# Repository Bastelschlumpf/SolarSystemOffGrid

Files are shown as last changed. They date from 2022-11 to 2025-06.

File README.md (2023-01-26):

## Off Grid Solar System
   **Solar system for use as an emergency power supply with automatic switching to mains power in case of lack of solar 
     power with display on an E-Ink display via MQQT.**

### Description
   The goal of this facility was to ask; what happens in the event of a power outage.  
   Which electrical devices in the house are the most critical here and should continue to function in this case.
   At least for some time.  
   In my case, this would be the freezers and the oil heating.
   A continued functioning of the solar circulation pump would also be beneficial.  
   What good are hundreds of liters of heating oil in the tank if the house remains cold because of the 200W that the oil burner needs.  
   On television, computer and also the short-time cooking on an electric stove should be able to be renounced to the emergency.  
   In addition, this system should monitor the battery capacity and in case the sun does not shine enough automatically switch to house power.  
   And since I am a Tasmota and ESP fan, the whole thing should be additionally monitored via E-Ink display and MQQT via my IoBroker.

### Disclaimer
   I don't take any responsibility nor liability for using this software nor for the 
   installation or any tips, advice, videos, etc. given by any member of this site or any related site.  
   Attention this plant is in the making and not yet tested.
   In particular, the behavior in summer months and the interaction with the batteries has not yet been tested by me
   extensively tested in practice. 

### Safety aspects
  * [Some thoughts about security](docs/SafetyAspects.md)

### Circuit
   Circuit diagram with pictures of the components   
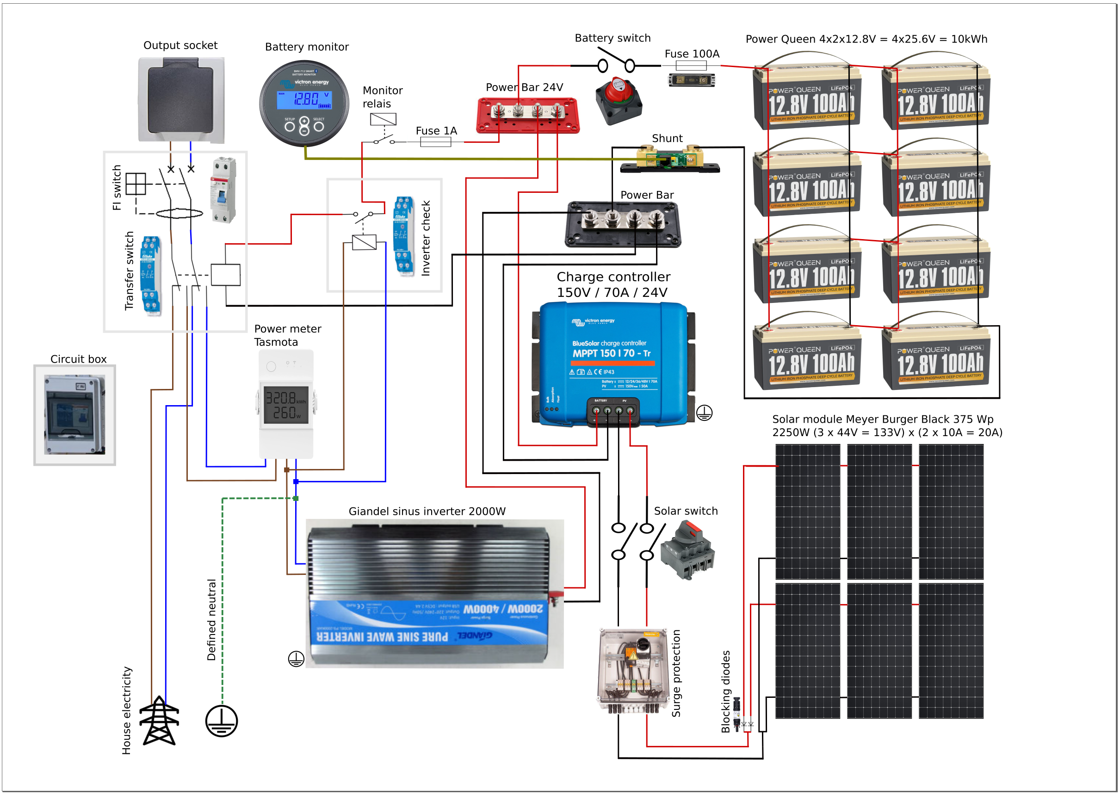
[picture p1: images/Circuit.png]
Circuit
   

   Circuit diagram with real components on the control panel
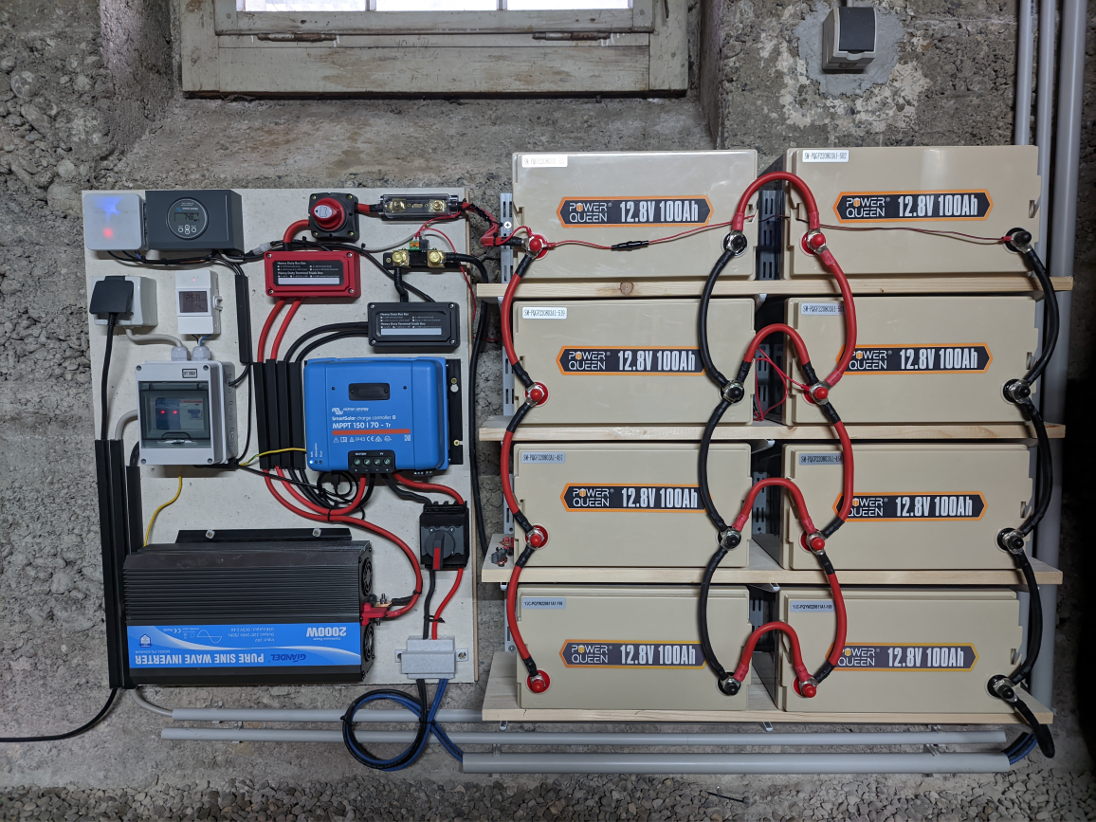
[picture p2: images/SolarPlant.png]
Circuit on the control panel Solar plant
     
   Manuals of the components: See manuals folder

### Pictures of the solar panels and installation
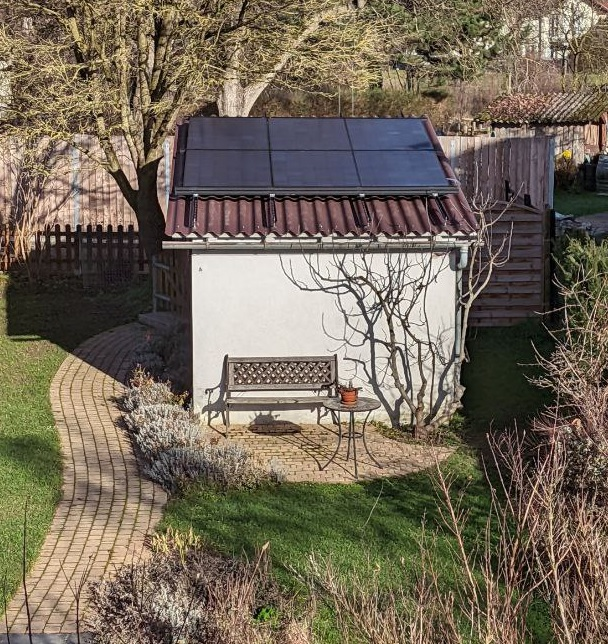
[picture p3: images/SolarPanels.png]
Solar panels
   

  * [See pictures of the installation](docs/TheSolarInstallation.md)

### Victron Modules and Settings
  * [See Victron modules and settings](docs/Victron.md)

### Power consumption monitoring with Tasmota
  * [See Tasmota (Sonoff) Elite 20A](docs/Tasmota.md)

### Victron MQQT Bridge to IoBroker
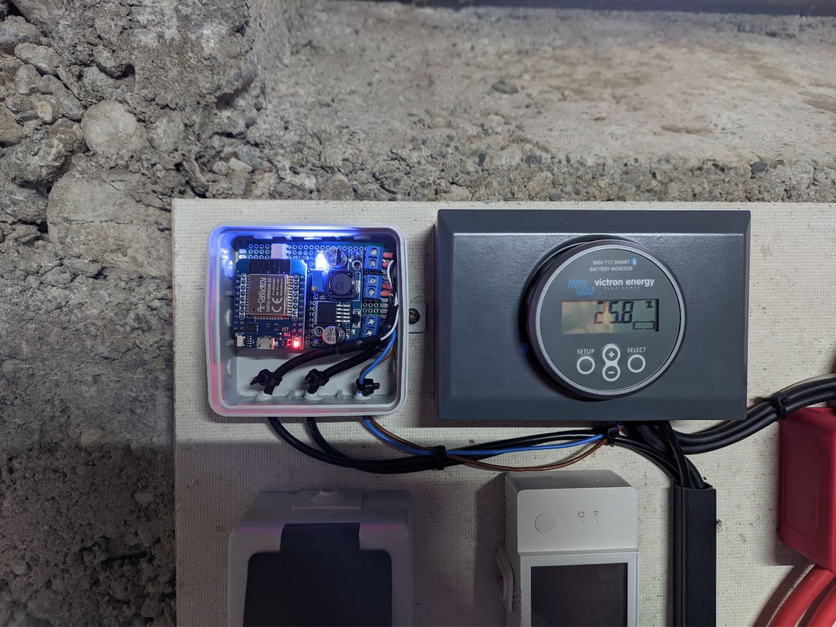
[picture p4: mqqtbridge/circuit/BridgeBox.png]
BridgeBox
   
   IoBroker View: Not beautiful but everything on it  
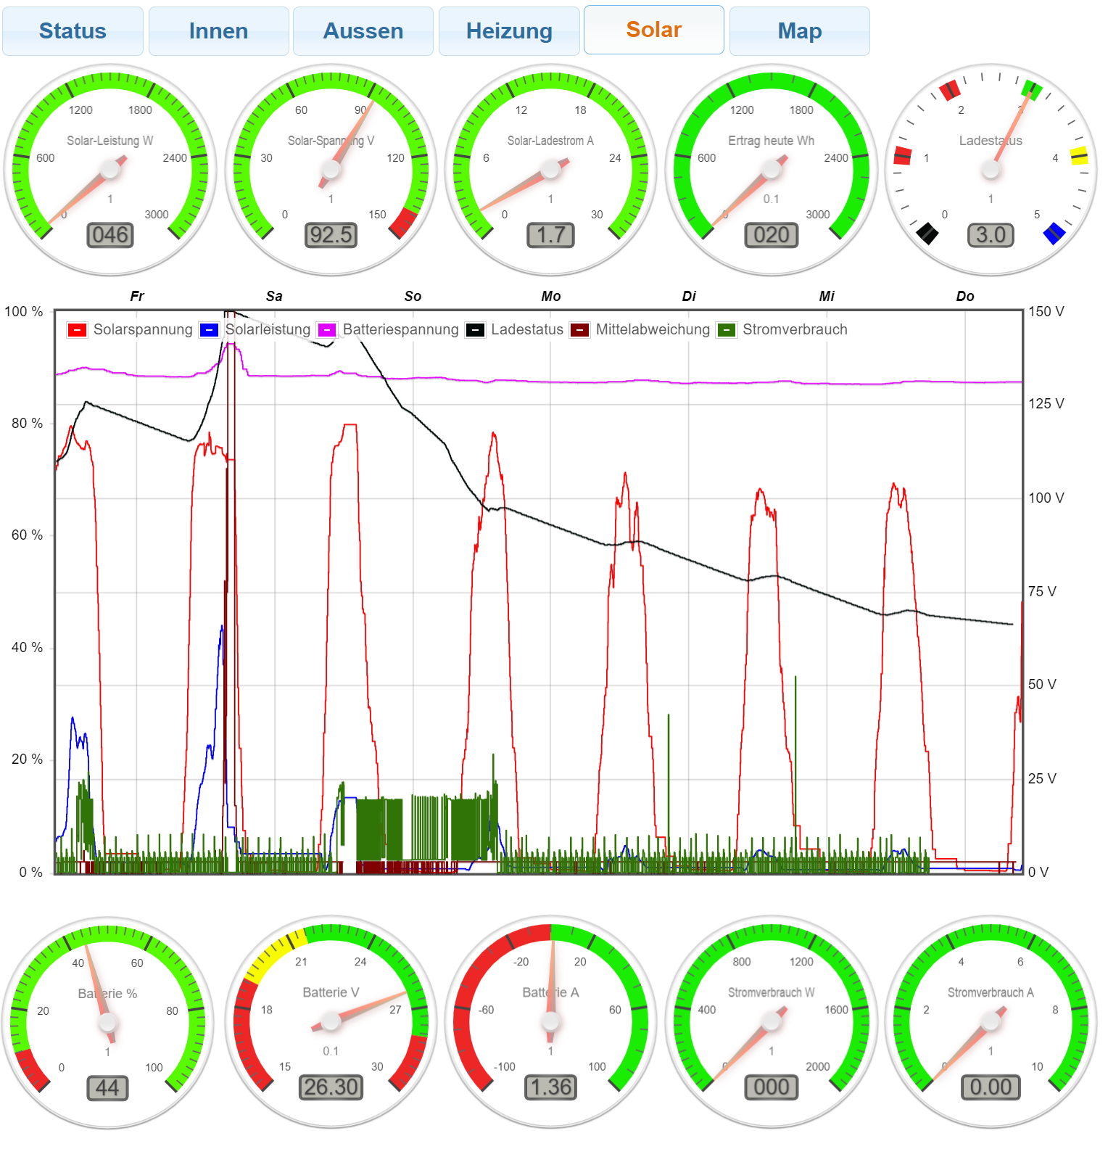
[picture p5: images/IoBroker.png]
IoBrokerView
   
  * [See Victron to IoBroker MQQT Bridge](docs/VictronMQQTBridge.md)

### Wall mounted status display via  E-Ink display (M5Paper)
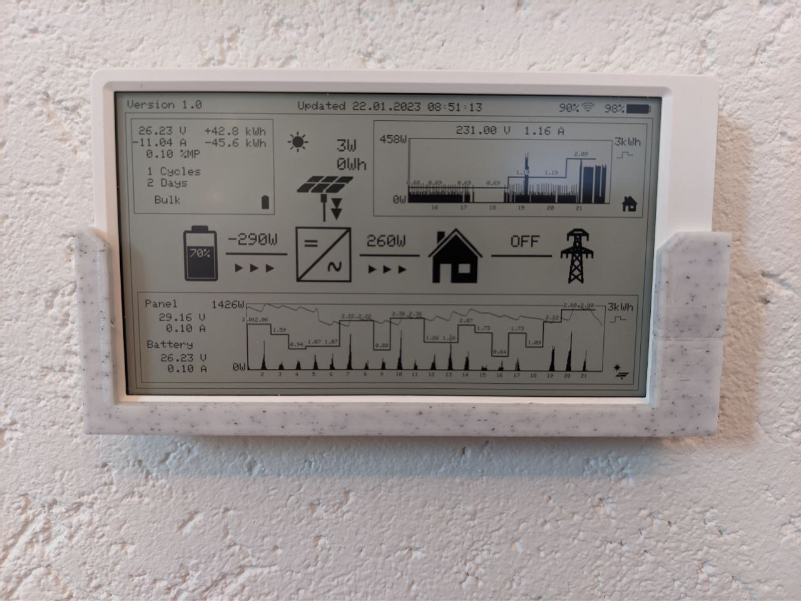
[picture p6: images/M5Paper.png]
Circuit M5Paper
   
  * [See Status display](docs/StatusDisplay.md)

### Shopping list
  * [See Shopping list](docs/ShoppingList.md)

### License
   This program is licensed under GPL-3.0

### Thanks
   * Thanks to 'Power Queen' for the great support and advice.
   * https://www.arduino.cc
     *Thanks to the Arduino community with all its incredible possibilities and support.** 
   * https://github.com/arendst/Sonoff-Tasmota
     *Thanks to Theo Arends for his great home automation software project with all the detailed esp functionality.*
   * http://fritzing.org/home
     *Thanks to the fritzing team for this very intuitive usable software.* 
     I could create my circuit in Fritzing with only a half day.
   * And a special thanks to the support of the local electrician for advice on solar issues and for the 
     Ordering electrical components like cables, surge protectors and solar panels.
     And many thanks for the energetic support of my brother in pulling cables, assembling
     components and also for the good advice.

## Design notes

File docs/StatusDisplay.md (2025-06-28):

## Status display via  E-Ink display (M5Paper)

### Compiling instraction

Board **M5Stack 2.1.4**

Library  
  **M5EPD 0.1.5 (https://github.com/m5stack/M5EPD)**  
  **RTCLib 2.1.4 (https://github.com/adafruit/RTClib)**  
  **Time 1.6.1 (https://playground.arduino.cc/Code/Time)**   
  Arduino flash with default settings

### Monitor description

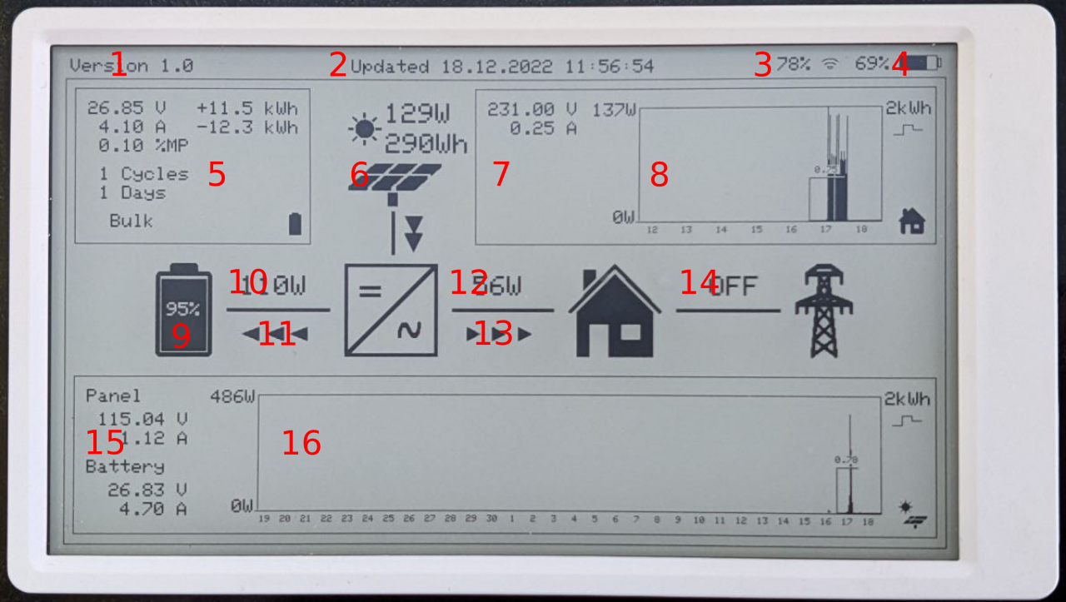
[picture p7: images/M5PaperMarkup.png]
Circuit M5Paper


The entire solar system should have a display on which all important status messages and values are visible.  
In addition, two diagrams about the power curve should be displayed.  
By simple symbols it should be directly recognizable in which direction the power is currently flowing and  
whether a connection is switched on or off.  
If errors occur in the battery monitor module or the charge controller,  
these should be displayed with priority.
Furthermore, it should be visible if the data is no longer supplied by the IoBroker or if it is outdated.  

Here is the description of each area.

|Label |Description |
|---|---|
|<span style="color: red">  1 </span>| Internal monitor version. |
|<span style="color: red">  2 </span>| The date and time of the last display update. |
|<span style="color: red">  3 </span>| The strength of the wifi connection with value and symbol. |
|<span style="color: red">  4 </span>| The current state of charge of the battery with value and symbol. |
|<span style="color: red">  5 </span>| All detailed information of the battery monitor (Victron BMV-712).
| | - The current voltage |
| | - The current charge or discharge current |
| | - The deviation of the average point voltage |
| | - How much charge was charged in total |
| | - How much charge has been removed in total |
| | - The number of charge cycles |
| | - How many days since the last full charge |
| | - The current charging mode |
| | In case of an error, the problem is displayed here instead. |
|<span style="color: red">  6 </span>| Display of the solar panel icon with the current watt and the power gained today |
|<span style="color: red">  7 </span>|  The details of output power monitoring (Tasmota Elite) |
| | - Grid voltage |
| | - Current current consumption |
|<span style="color: red">  8 </span>| Statistical data of consumed energy for the last 7 days (watts and kWh) |
|<span style="color: red">  9 </span>| The battery icon with the current charge level |
|<span style="color: red"> 10 </span>| The current charging (+) or discharging (-) power. |
|<span style="color: red"> 11 </span>| Arrow direction of loading or unloading |
|<span style="color: red"> 12 </span>| The current energy going to the end users. |
|<span style="color: red"> 13 </span>| The arrows indicate whether the final consumers are supplied by the solar system. |
|<span style="color: red"> 14 </span>| The arrows indicate whether the end users draw power from the grid otherwise 'OFF'. |
|<span style="color: red"> 15 </span>| All detailed information of the charge controler (Victron MPPT 150/70). |
| | The voltage of the solar panels |
| | The delivered current of the solar panels |
| | The current battery charging voltage |
| | The current battery charging current |
|<span style="color: red"> 16 </span>| Statistical data of the charge controller in watts and kWh and the battery charge. |

### Wall mount

And here the whole thing with a wall mount made by 3D printing

   See https://www.thingiverse.com/thing:4767014  
   Wall mount WallMount

### Inplate 6 Plus version

   I have also ported the M5Paper version to Inkplate 6 Plus for testing.
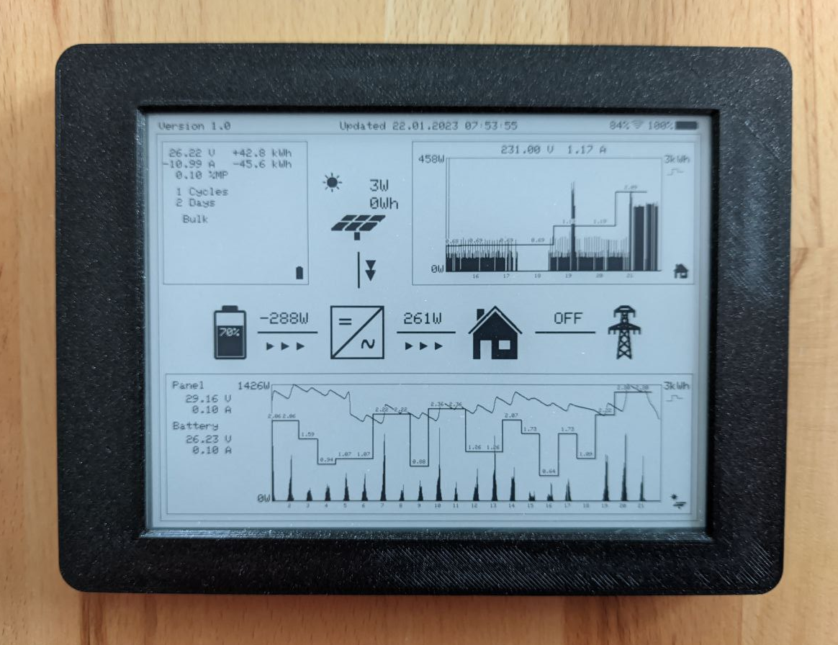
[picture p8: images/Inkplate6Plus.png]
Inkplate 6 Plus


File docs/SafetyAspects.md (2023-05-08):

### Some thoughts about security

- The solar panels are protected against lightning strikes by an overvoltage protection.
- The parallel connected solar panels are protected by a blocking diode so that the current does not flow into the other series connection.
- Directly after the solar panels a circuit breaker is installed in the garage so that the solar voltage can be disconnected from the grid on site.
- The solar connection line in the basement also has a circuit breaker so that the solar voltage can also be disconnected in the basement.
- The solar charge controller has reverse polarity protection, overload protection and temperature protection and also switches off automatically in case of other errors.
- The battery monitor monitors the battery voltage, charge and discharge current, as well as the midpoint voltage and temperature of the battery bank.
- The inverter has overvoltage protection, undervoltage protection and temperature monitoring.
- The batteries have an integrated battery management system. This protects each battery from overvoltage, undervoltage, overtemperature and undertemperature below 0 degrees Celsius.
- In addition, the battery management system also protects against short circuit.
- The battery bank can be disconnected from the system by a power disconnect switch.
- The battery bank connection is protected by a 100A fuse from the system.
- The power switching relay circuit and the supply voltage of the battery monitoring system is protected against short circuit by a 1A fuse.
- The output of the inverter is protected against fault currents by a RCD fuse.
- The output of the inverter can be remotely disconnected from the grid via a power monitoring system via Wifi.
- According to the installation connection standard and so that the RCD is functional, one phase of the inverter is defined by means of grounding to a defined potential.
- The complete system sends its status data to a home control system (IoBroker).
- An E-Ink display shows all important system data and statistics.
- The circuit is fireproof mounted on a Fermacell panel.
- The connections with higher voltage are covered finger-safe.
- A fire alarm is mounted in the basement room.
- Furthermore, a special extinguisher for lithium-ion batteries is mounted in some distance.

I hope I have not overlooked anything fundamentally important.

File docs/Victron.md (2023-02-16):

### Victron Modules and Settings

I use 2 modules from Victron.
A charge controller (SmartSolar MPPT 150/70) to bring the solar energy of the solar panels into the battery and  
 a battery monitor (Smart BMV-712) that monitors the state of charge of my batteries by means of a shunt.

Victron BMV-712 with enhousing  
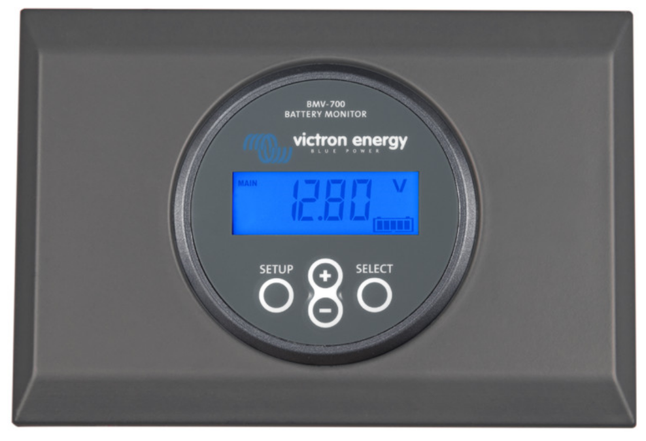
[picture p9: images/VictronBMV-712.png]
Victron BMV-712 Smart BMV


Victron BMV-712 shunt  
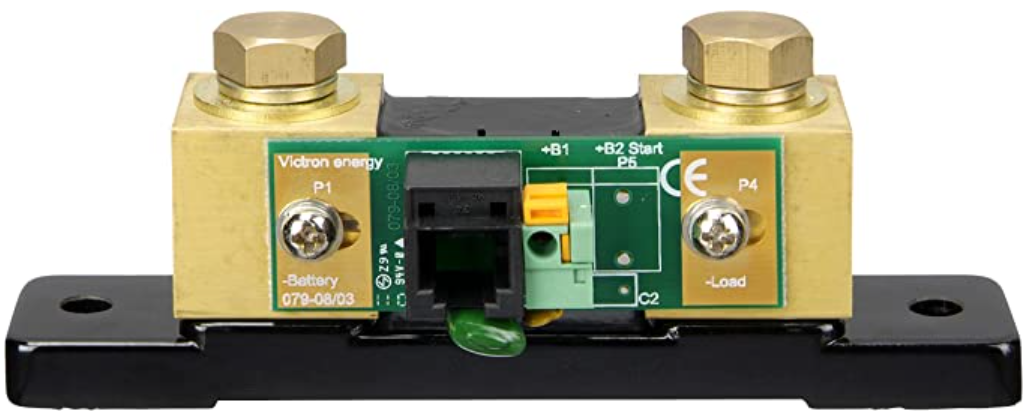
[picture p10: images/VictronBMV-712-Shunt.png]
Victron BMV-712 shunt Smart BMV


Victron Smart Battery Monitor  
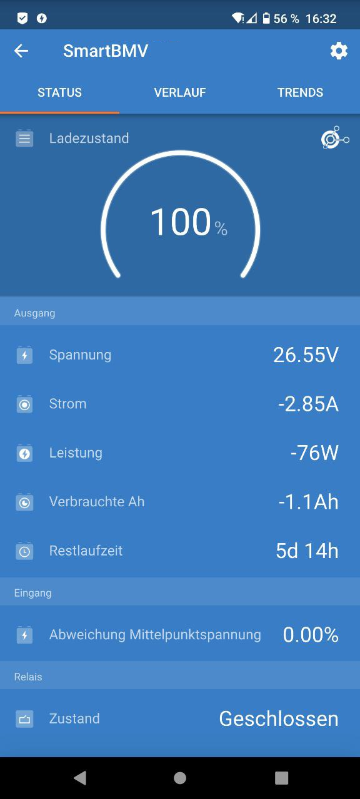
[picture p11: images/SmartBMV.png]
Victron BMV Monitor Smart BMV


Victron Smart MPPT 150/70  
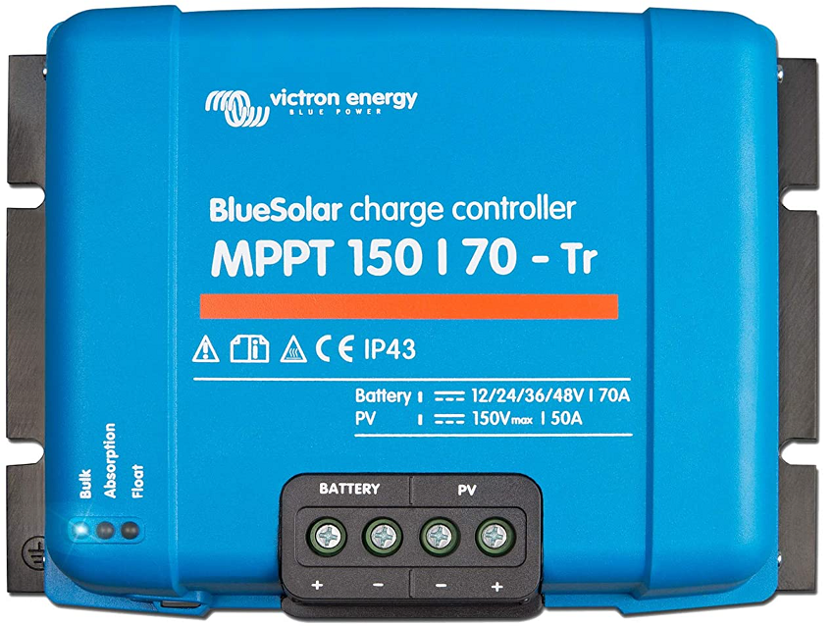
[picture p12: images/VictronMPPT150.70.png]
Victron MPPT Smart MPPT


Victron Smart MPPT Monitor  
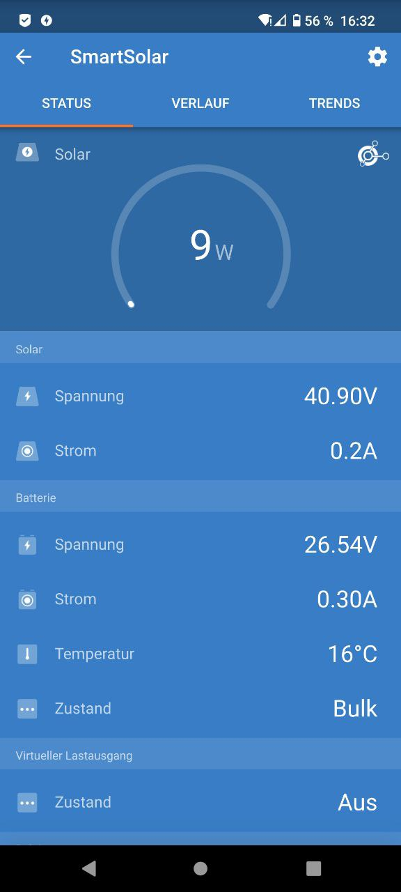
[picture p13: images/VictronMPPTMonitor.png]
Victron MPPT Monitor Smart MPPT Monitor


### Smart MPPT 150/70 Settings

|Name |Value |Description  |
|-----|---|---|
|Battery voltage |24V |2 times each Power Queen Lifepo4 Battrien in series |
|Max charge current | 70A | The Power Queen batteries can handle max 100A charge currents but the charge controller can only handle max 70A |
|Charger enabled | enabled | To safe the power in the batteries |
|Battery preset | Power Queen | I make a copy of the LiFePo4 settings and have given their own name 'Power Queen'. |
|Absorption voltage | 28.8V | In the description of Power Queen it says 'Recommended charging voltage 14.2V to 14.6V therefore 2 times 14.4V = 28.8V |
|Float voltage | 27.6V | In the description of Power Queen it says 'float charge voltage 13.8V therefore 2 times 13.8V = 27.6V |
|Equalization voltage | disabled | Disabled for LiFePo4 battries |
|Expert settings |  |  |
|Re-bulk voltage offset | 1.8V | Recommend 27V for re-bulk so it will be 28.8V - 1.8V = 27V. |
|Absorption duration | adaptive | Recommend adataptive for Power Queen |
|Absorption time | 2h | Should be enough |

### Smart BMV-712 Settings

|Name |Value |Description  |
|-----|---|---|
|Battery capacity | 400Ah | 4 x 2 x 100Ah Power Queen LiFePo4 batteries = 400Ah |
|Charged voltage | 27V | According to the Power Queen documentation, the voltage at 100% is 13.5V, i.e. times 2 = 27V. |
|Discharge floor | 20% | LiFePo4 batteries can be discharged up to 20%. |
|Tail current | 2.0% | 2% at 400Ah = 8A should be enough to switch to float. |
|Charged detection time | 3m | Should be enough. |
|Peukert exponent | 1.05 | Special value for LiFePo4 batteries. |
|Charge efficiency factor | 99% | Special value for LiFePo4 batteries. |
|Current threshold | 0.10A | Default for LiFePo4 batteries. |
|Time-to-go averaging period | 12m | Especially maximum (12m) since in refrigerators very changeable power demand. |
|Relais settings |  |  |
|Relais-Modus | Standard |  |
|Relais inverted | yes | In the event of a battery power failure, the system automatically switches to mains power. |
|Relay low charge | 10% - 90% | I.e. if the battery charge drops below 10% then the relay opens and the system goes on mains power until the charge is back to 90%. |

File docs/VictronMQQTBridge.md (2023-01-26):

### Victron MQQT Bridge

   **A bridge to send all the victron ve.direct data to my IoBroker via MQQT**
   
   The bridge should be connected by optocouplers galvanically isolated to both Victron devices, 
   the MPPT charge controller and the battery monitoring device.

   The software should read both ve.direct ports, respect the checksum so that no data garbage 
   arrives at my IoBroken and then send only every 10 seconds to the ioBroker.

   Circuit diagram with pictures of the components   
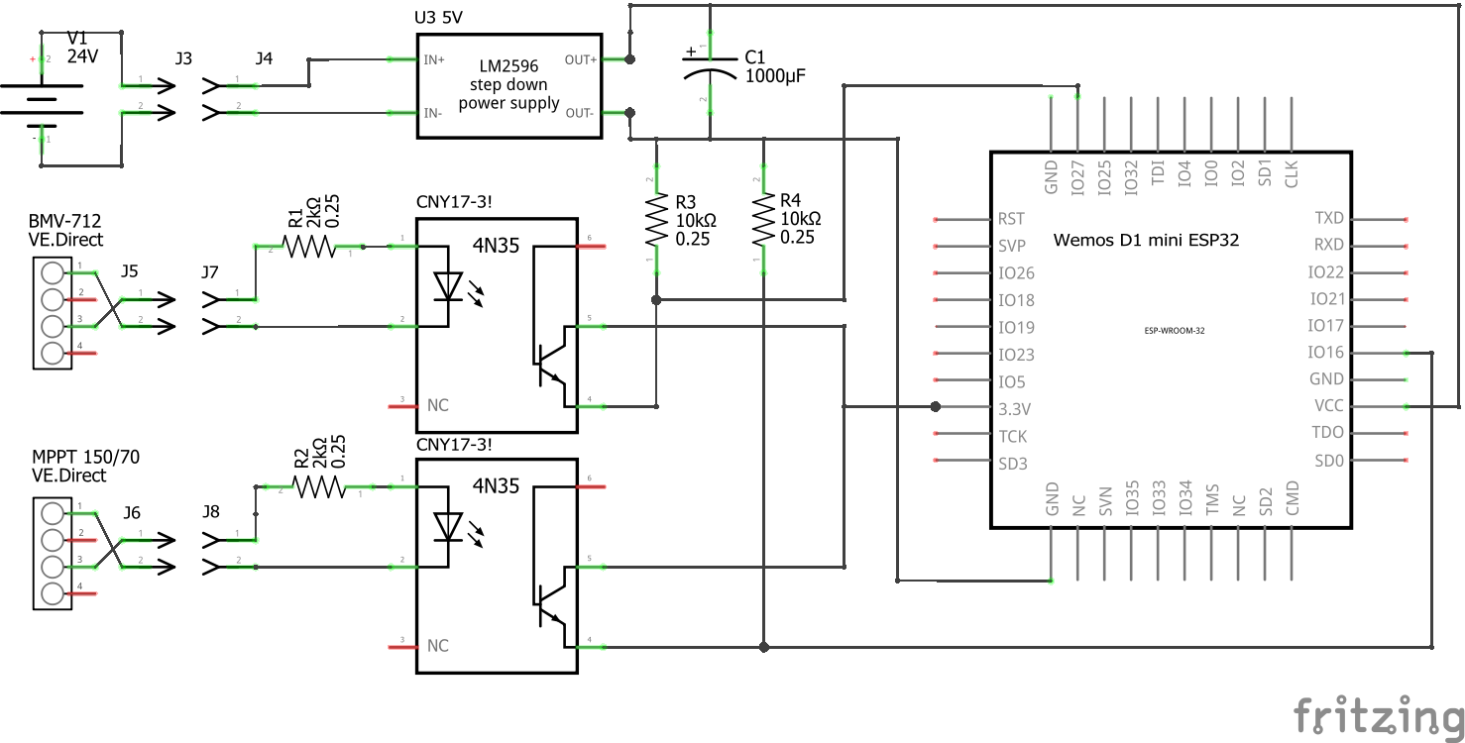
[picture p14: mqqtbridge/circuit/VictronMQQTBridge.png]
Victron To MQQT Bridget Victron To MQQT Bridge
   
   I had problems with the 4N35 optocoupler but with the CNY17-3 it works fine.  
   And very important: The LM2596 is great but the output voltage must be smoothed, 1000μF is a bit much but never mind.

   Finished Board  
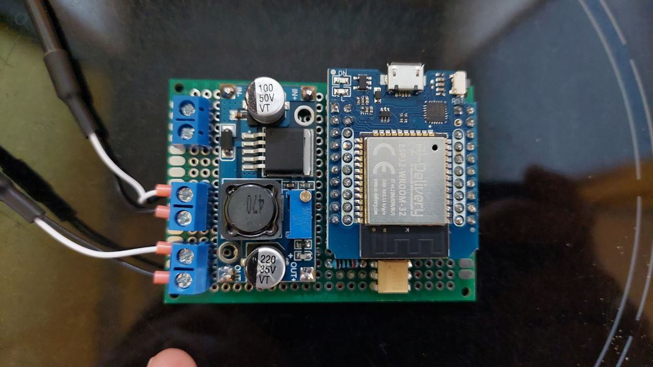
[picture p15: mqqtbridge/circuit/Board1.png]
Board1 Board 1
   

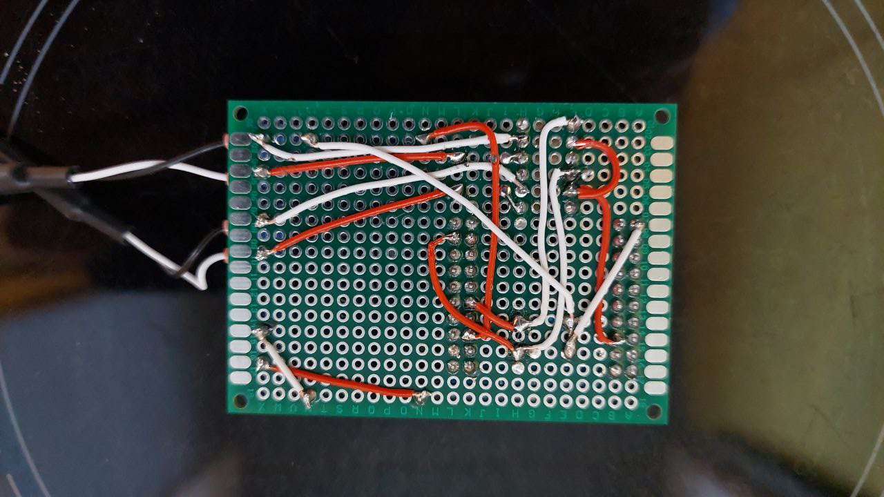
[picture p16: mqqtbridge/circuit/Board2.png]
Board2 Board 2
   
   I used a Victron VE.Direct TX digital output cable.

   On the subject of connecting the ve.direct interface via Optocopler, I found this page. 
   https://www.tarthorst.net/victron-ve-direct/  
   Thank you for this example.  
   I have modified it a bit, I now switch the 3.3V input then I do not have to invert the signal.  
   And I tested the series resistor. It works best with 2k ohms at the optocoupler input and 10k ohms at the ESP32 input

   The box at the solar installation
   BridgeBox

   The data packets arrive in my IoBroker.
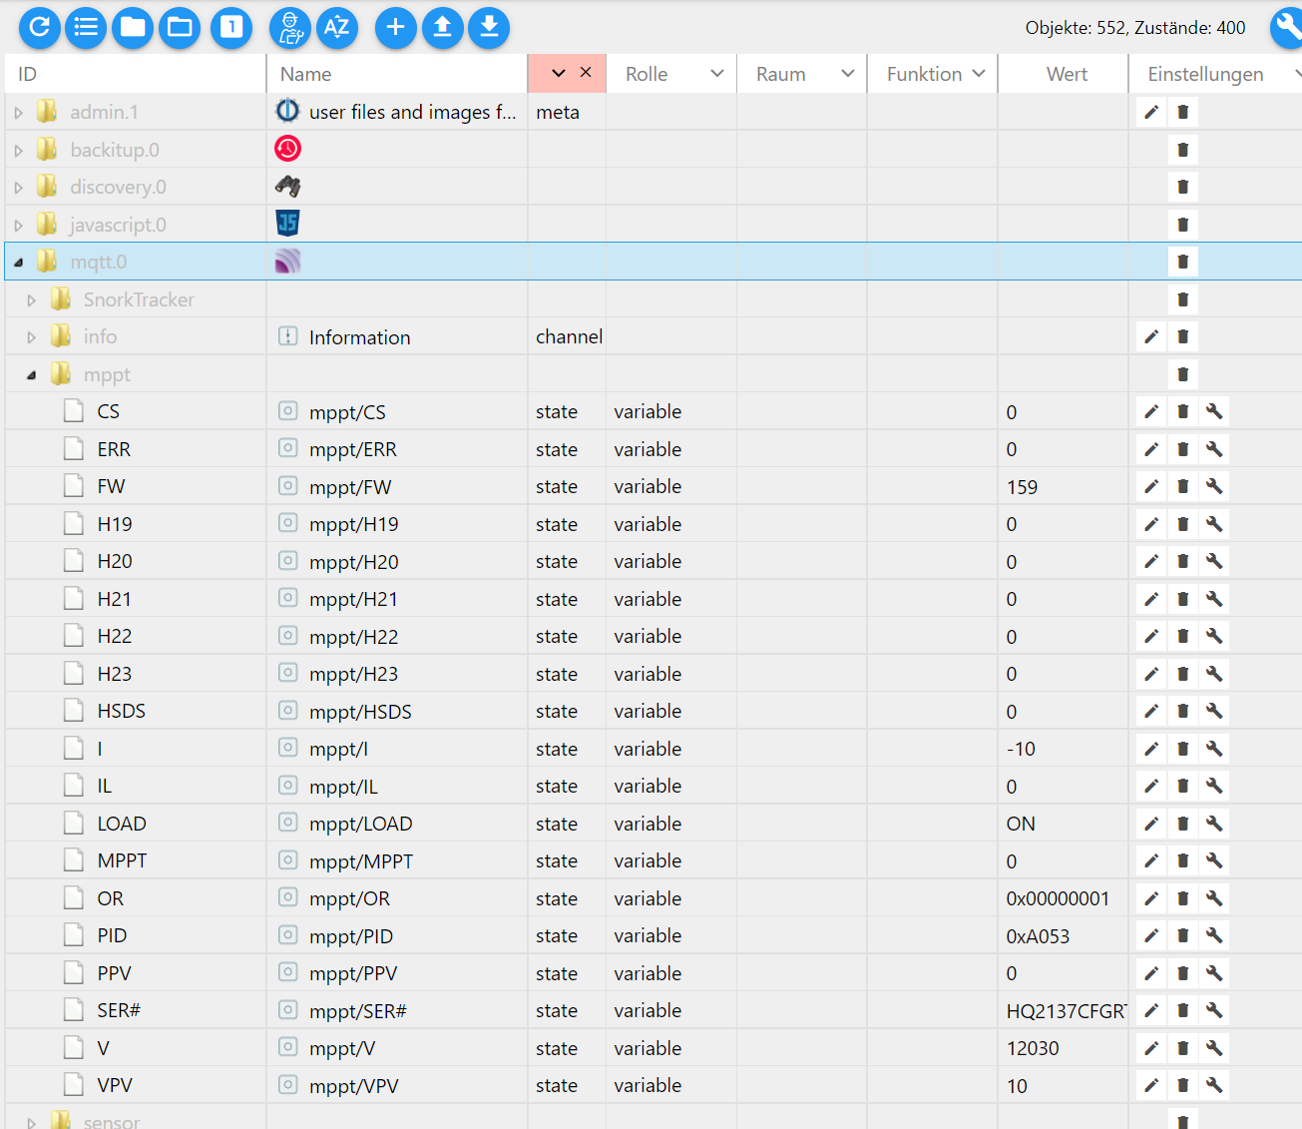
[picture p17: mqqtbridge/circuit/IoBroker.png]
Board2 IoBroker
   

   IoBroker View: Not beautiful but everything on it  
   IoBrokerView

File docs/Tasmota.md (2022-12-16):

### Tasmota (Sonoff) Elite

To monitor power usage, I reflashed a Sonoff POW320D with the Tasmota software.  
This module has an integrated LCD display of the power values and can send the data to my IoBroker via Mqtt.

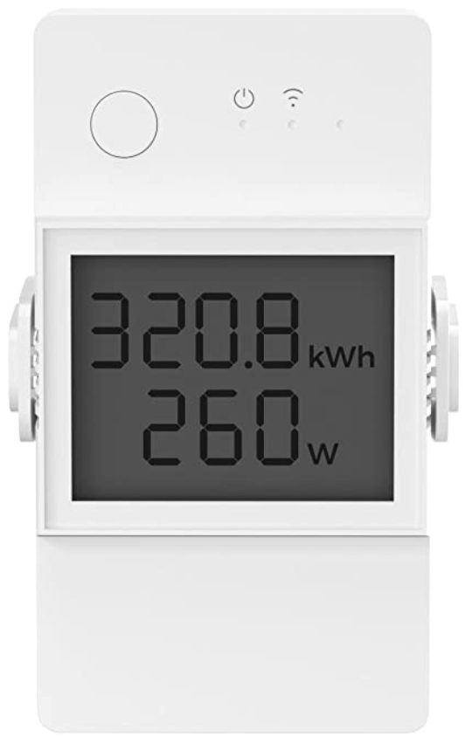
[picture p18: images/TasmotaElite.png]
Tasmota Powermeter Powermeter


A good description how to write the tasmota software to the Sonoff can be found here:  
https://bangertech.de/sonoff-pow-elite/

The display directly via Wifi then looks something like this  
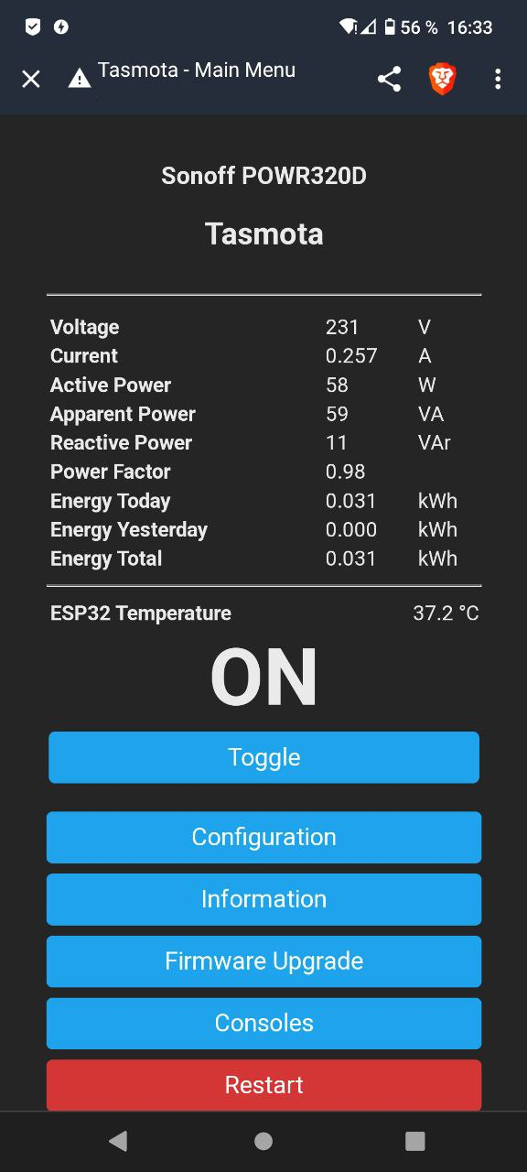
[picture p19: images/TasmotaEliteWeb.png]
Tasmota Powermeter Web Powermeter Web


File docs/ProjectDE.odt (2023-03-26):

Projektbeschreibung Inselsolaranlage

Inselsolaranlage mit 24V Batteriebank, Laderegler und Wechselrichter. Unterstützt durch einen Batteriemonitor, Leistungstrennschalter und einem Netzvorrangschalt-Relais im Falle einer Unterversorgung durch die Batterien oder abgschaltetem Wechselrichter.

- Solarmodule: 6 x Meyer Burger Black 375 Wp = 2250W (3 * 44V = 133V) * (2 * 10A = 20A)
- Solar-Anschlussbox Weidmüller (DC-Überspannungsschutz mit Solar-Last-Trennschalter)
- Zusätzlicher Solar-Last-Trennschalter (max. 500V, 32A) an der Anlage im Haus
- Victron SmartSolar MPPT Solarladeregler 150/70 TR 24V 150V PV 70A
- Zusatzsicherung (100A) vor den Batterien.
- Batterie-Last-Trennschalter (max. 48V, 275A)
- Power Queen LiFePO4 (100Ah 12V zu 4 x 2 x 12V = 4 x 24V * 100Ah = 10kWh)
- Victron Batterie-Monitor BMV-712 Smart zur Überwachung der Batterie des Verbrauchs und des Ladezustandes
- Wechselrichter (Giandel PS2000KAR-24V Reiner Sinus 2000W)
- Netzvorrangrelais zum Umschalten auf Netzbetrieb bei fehlender Wechselrichterspannung.
- FI-Schutzschalter (ABB F202 A-25/0.03, 25A 30mA)

Sicherheitsaspekte

Elektrisch

- Die Solarpaneele sind mit einem Überspannungsschutz gegen Blitzeinschlag gesichert.
- Die parallel geschalteten Solarpaneele sind durch eine Sperrdiode geschützt damit der Strom nicht in die andere Reihenschaltung fliesst.
- Direkt nach den Solarmodulen ist ein Leistungsschalter in der Garage angebracht damit die Solarspannung schon vor Ort vom Netz genommen werden kann.
- Die Solaranschlussleitung im Keller hat ebenfalls ein Leistungsschalter damit auch im Keller die Solarspannung getrennt werden kann.
- Der Solarladeregler hat einen Verpolungsschutz, Überlastschutz und einen Temperaturschutz und schaltet bei sonstigen Fehlern ebenfalls automatisch ab.
- Der Batteriemonitor überwacht die Batteriespannung, den Lade- und Entladestrom sowie die Mittelpunktspannung und die Temperatur der Batteriebank.
- Der Wechselrichter hat einen Überspannungsschutz, Unterspannungsschutz und eine Temperaturüberwachung
- Die Batterien haben ein integriertes Batteriemanagementsystem. Dieses schützt jede einzelne Batterie vor Überspannung, Unterspannung, Übertemperatur und Untertemperatur unter 0 Grad Celsius
- Ausserdem schützt das Batteriemanagementsystem auch vor Kurzschluss
- Die Batteriebank ist durch einen Leistungstrennschalter vom System trennbar.
- Der Anschluss der Batteriebank ist durch eine 100A Sicherung vom System abgesichert.
- Die Netzumschalt-Relais Schaltung und die Versorgungsspannung der Batterieüberwachung ist durch eine 1A Sicherung gegen Kurzschluss abgesichert.
- Der Ausgang des Wechselrichters ist durch eine FI-Sicherung gegen Fehlerströme abgesichert.
- Der Ausgang des Wechselrichters ist über eine Leistungsüberwachung via Wifi vom Netz per Ferne trennbar.
- Das komplette System sendet seine Zustandsdaten zu einer Haussteuerung (IoBroker)
- Ein E-Ink Display zeigt alle wichtigen Systemdaten und Statistiken an.
- Die Anschlüsse mit höherer Spannung sind Finger-sicher abgedeckt.

Sonstiges

- Die Schaltung ist feuerfest auf einer Fermacellplatte montiert.
- Im Kellerraum ist ein Feuermelder angebracht.
- Ausserdem ist in etwas Entfernung ein spezieller Sonderlöscher für Lithium-Ionen-Akkus angebracht.

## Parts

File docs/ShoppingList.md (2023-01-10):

### Shopping list

Here are some sample shopping items. Please check the details if everything is correct.

|Label |Price / unit |Sample URL |
|---|---|---|
|1 x Glued wood board 80cm x 60cm | ? | DIY store |
|1 x Fermacel plate 60cm x 80cm (fire protection) | ? | DIY store |
|8 x Power Queen LiFePo4 100Ah | 474€ | https://www.amazon.de/gp/product/B0BGSHCSK6/ref=ppx_yo_dt_b_search_asin_title?ie=UTF8&psc=1 |
|1 x Victron MPPT 150/70 Tr | 600€ | https://www.amazon.de/gp/product/B07B4K62LN/ref=ppx_yo_dt_b_search_asin_title?ie=UTF8&psc=1|
|1 x Victron BMV-712 | 170€ | https://www.amazon.de/gp/product/B075RTSTKS/ref=ppx_yo_dt_b_search_asin_title?ie=UTF8&psc=1|
|1 x Victron BMV-712 housing | 30€ | https://www.amazon.de/gp/product/B019FZW53K/ref=ppx_yo_dt_b_search_asin_title?ie=UTF8&psc=1|
|1 x Giandel pure sine wave inverter 2000W 24V | 320€ | https://www.amazon.de/gp/product/B07QDMZ7QS/ref=ppx_yo_dt_b_search_asin_title?ie=UTF8&psc=1|
|1 x surge protection Weidmüller | 400€ | |
|1 x Sonoff POW320D Elite | 45€ | https://www.amazon.de/gp/product/B09XB3RZB9/ref=ppx_yo_dt_b_search_asin_title?ie=UTF8&psc=1 |
|2 x Heavy duty bus bar | 40€ | https://www.amazon.de/gp/product/B09H6FSTW9/ref=ppx_yo_dt_b_search_asin_title?ie=UTF8&psc=1 |
|1 x Battery switch | 20€ | https://www.amazon.de/gp/product/B095JN7QHB/ref=ppx_yo_dt_b_asin_title_o04_s00?ie=UTF8&psc=1|
|1 x Circuit Braker Solar | 40€ | https://www.amazon.de/dp/B0BGPHJG3K?ref=ppx_yo2ov_dt_b_product_details&th=1 |
|1 x Fuse | 12€ | https://www.amazon.de/gp/product/B0B7LGFT7Z/ref=ppx_yo_dt_b_search_asin_title?ie=UTF8&psc=1|
|1 x FI circuit breaker | 30€ | https://www.amazon.de/gp/product/B001L5SLP4/ref=ppx_yo_dt_b_search_asin_title?ie=UTF8&psc=1|
|2 x Eltako switching relay, 2 changeover contacts  | 40€ | https://www.amazon.de/gp/product/B000UWEXE2/ref=ppx_yo_dt_b_asin_title_o00_s00?ie=UTF8&psc=1|
|1 x Circuit breaker box | 50€ | https://www.amazon.de/gp/product/B09VXTNZZX/ref=ppx_yo_dt_b_search_asin_title?ie=UTF8&th=1|
|1 x Socket damp room | 5€ | https://www.amazon.de/dp/B001BAZLK2/ref=redir_mobile_desktop|
|? x Battery cable| 13€/m | https://www.amazon.de/gp/product/B08YPDB4LL/ref=ppx_yo_dt_b_search_asin_title?ie=UTF8&th=1|
|? x Tubular cable lug | 1.2€ | https://www.amazon.de/gp/product/B074V9PLS9/ref=ppx_od_dt_b_asin_title_s00?ie=UTF8&psc=1|
|? x Cable channel | | |
|? x Cable | | |
|? x Screws | | |
|Solarpanel | | |
|6 x Meyer Buerger Solar panel 375Wp| 320€ | |
|2 x Blocking diode MC4 | 9€| https://www.amazon.de/gp/product/B09RH4VBC6/ref=ppx_yo_dt_b_asin_title_o01_s00?ie=UTF8&psc=1|

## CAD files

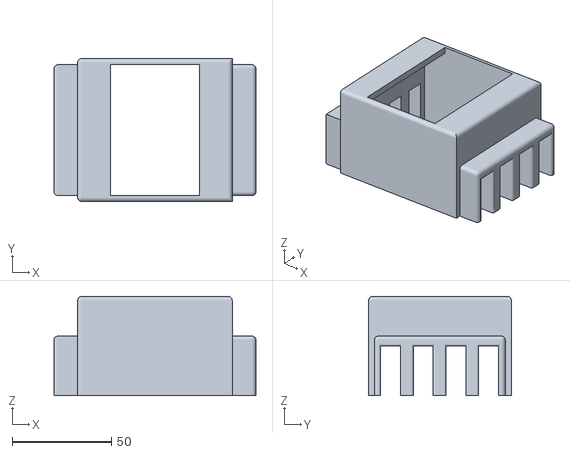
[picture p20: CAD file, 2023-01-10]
images/CircuitBrakeBox.stl
101.9 x 72.0 x 50.0

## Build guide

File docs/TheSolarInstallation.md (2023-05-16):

### Pictures of the solar installation

   Solar panels.  
   The final 6 xMeyer Burger solar panels.
   Solar panels

   Surge protection and solar panel main switch.  
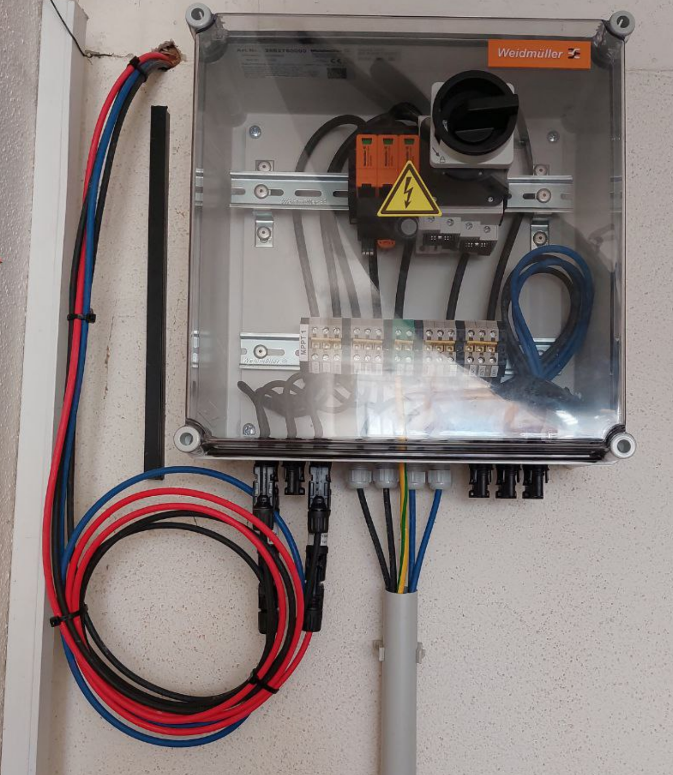
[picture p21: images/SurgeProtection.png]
SurgeProtection Surge protection
   

   Solar installation circuit  
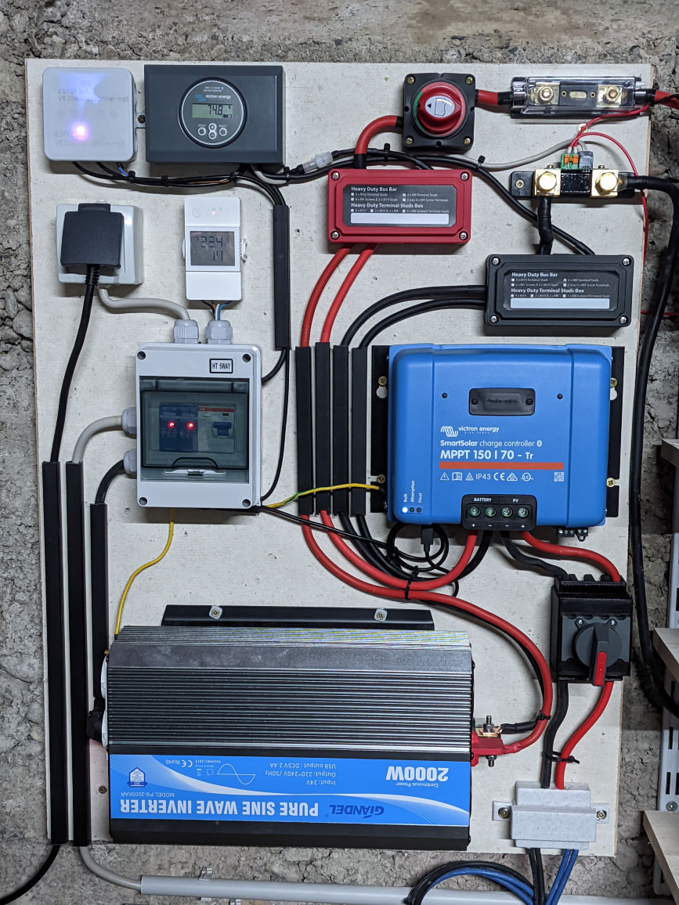
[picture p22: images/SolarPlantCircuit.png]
Solar plant circuit
   

   Solar installation battery pack  
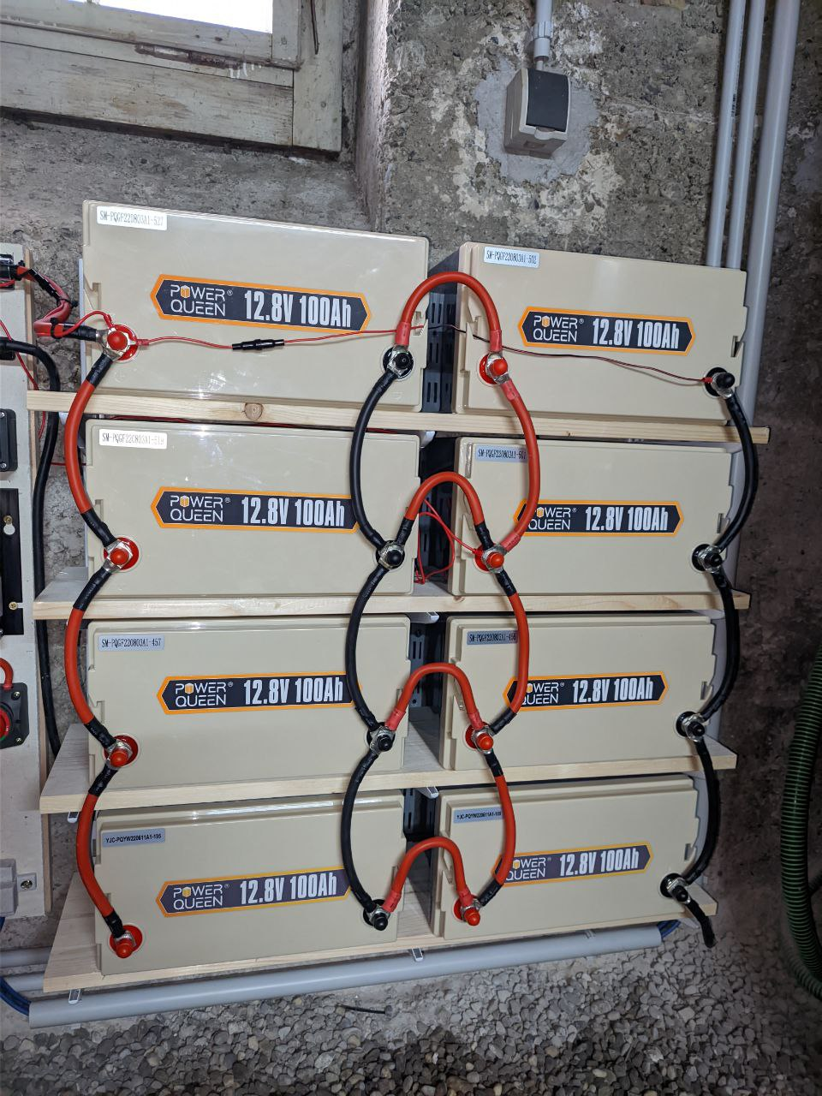
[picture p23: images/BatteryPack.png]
Solar plant battery pack
   

   Solar installation with battery pack
   Solar plant
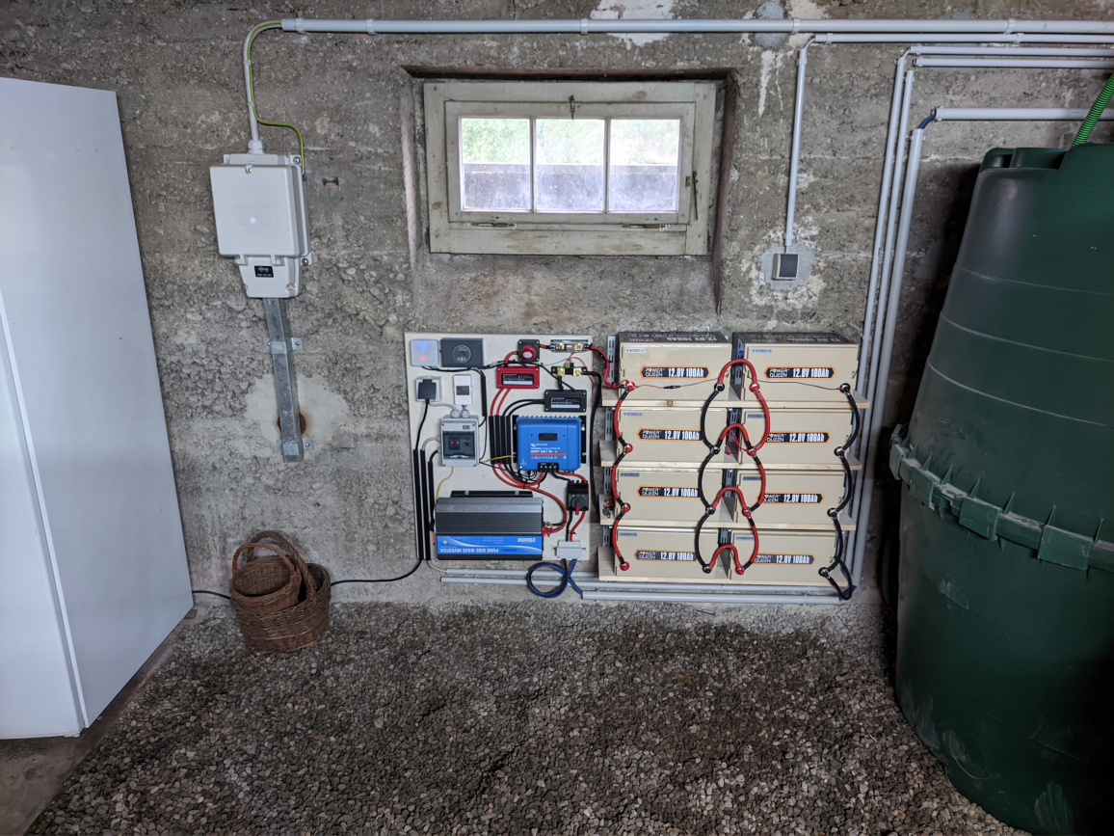
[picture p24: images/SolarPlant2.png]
Solar plant 2
   

   The pols of the batteries must be covered from accidental contact.
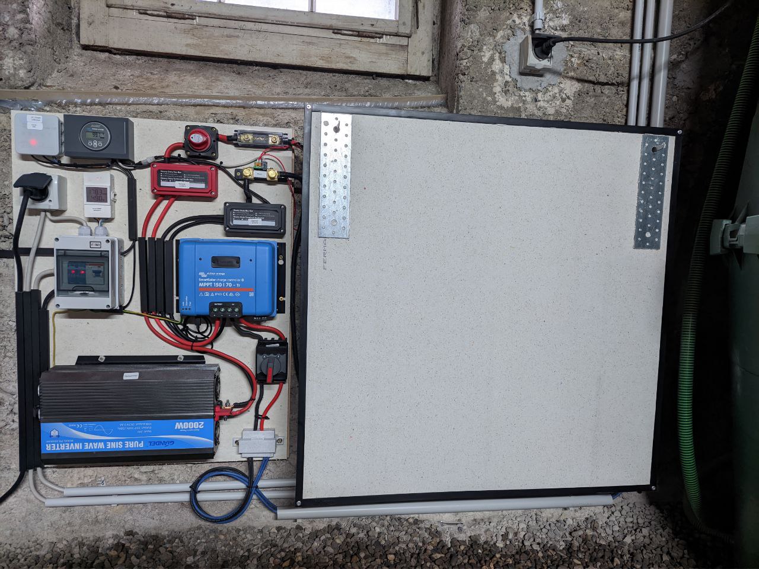
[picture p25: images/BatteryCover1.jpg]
BatteryCover1
   
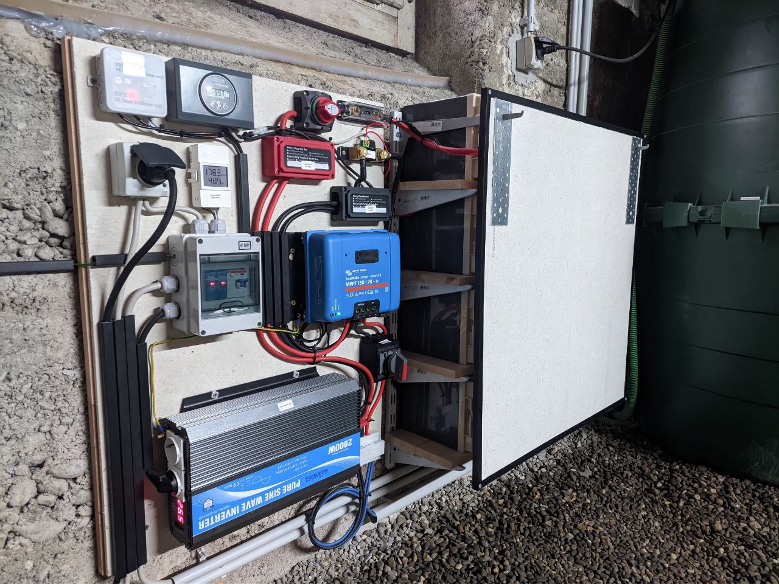
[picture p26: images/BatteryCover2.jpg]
BatteryCover1 BatteryCover2
   

   Thermo images ofv the circuit in action.  
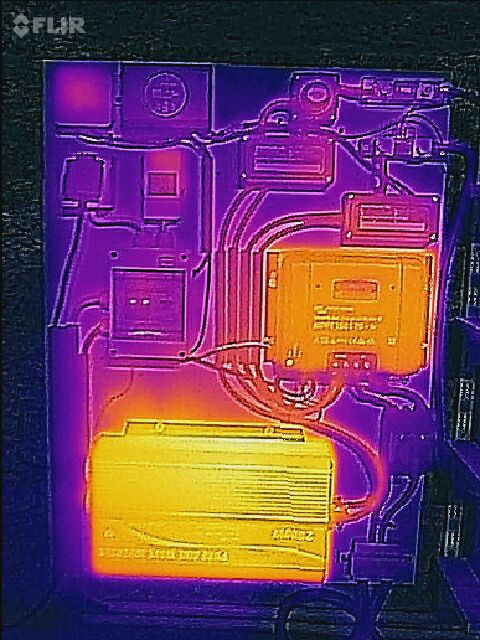
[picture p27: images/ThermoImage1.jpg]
ThermoImage1
   
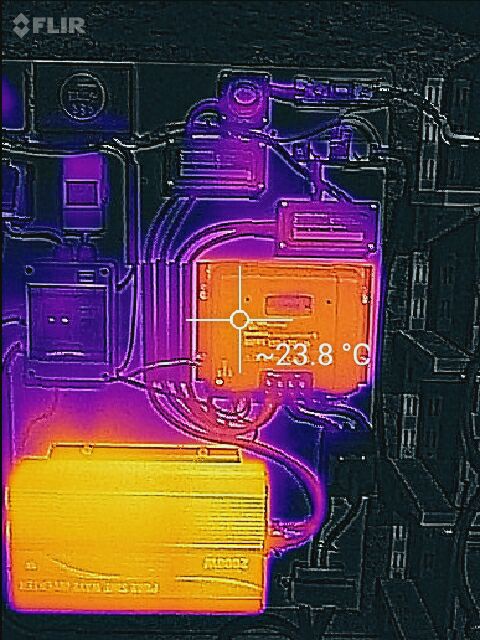
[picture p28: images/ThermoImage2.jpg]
ThermoImage2
   
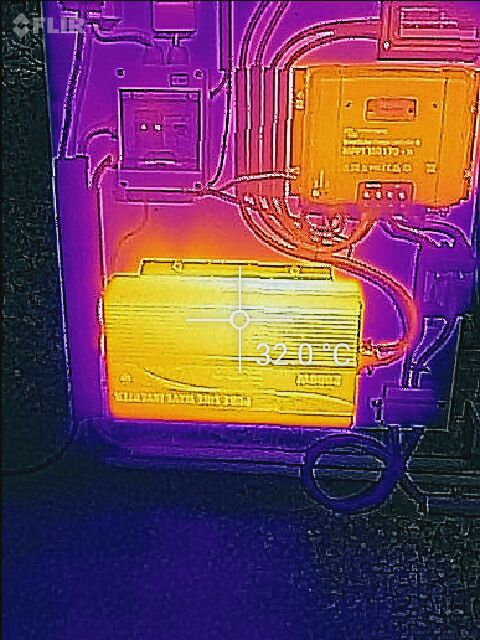
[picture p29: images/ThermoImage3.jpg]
ThermoImage3
   

   Solar Circuit Breaker Cover Box
   The circuit breaker needs a touch-proof cover
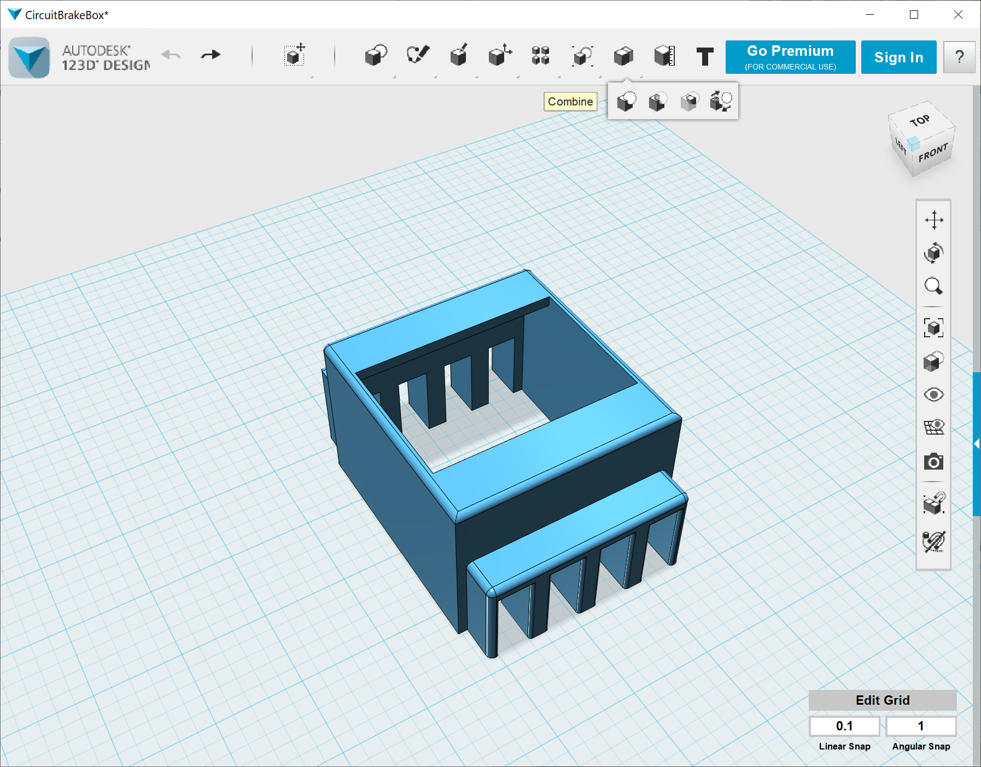
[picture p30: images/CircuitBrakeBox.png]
Breaker Box Circuit Breaker Box


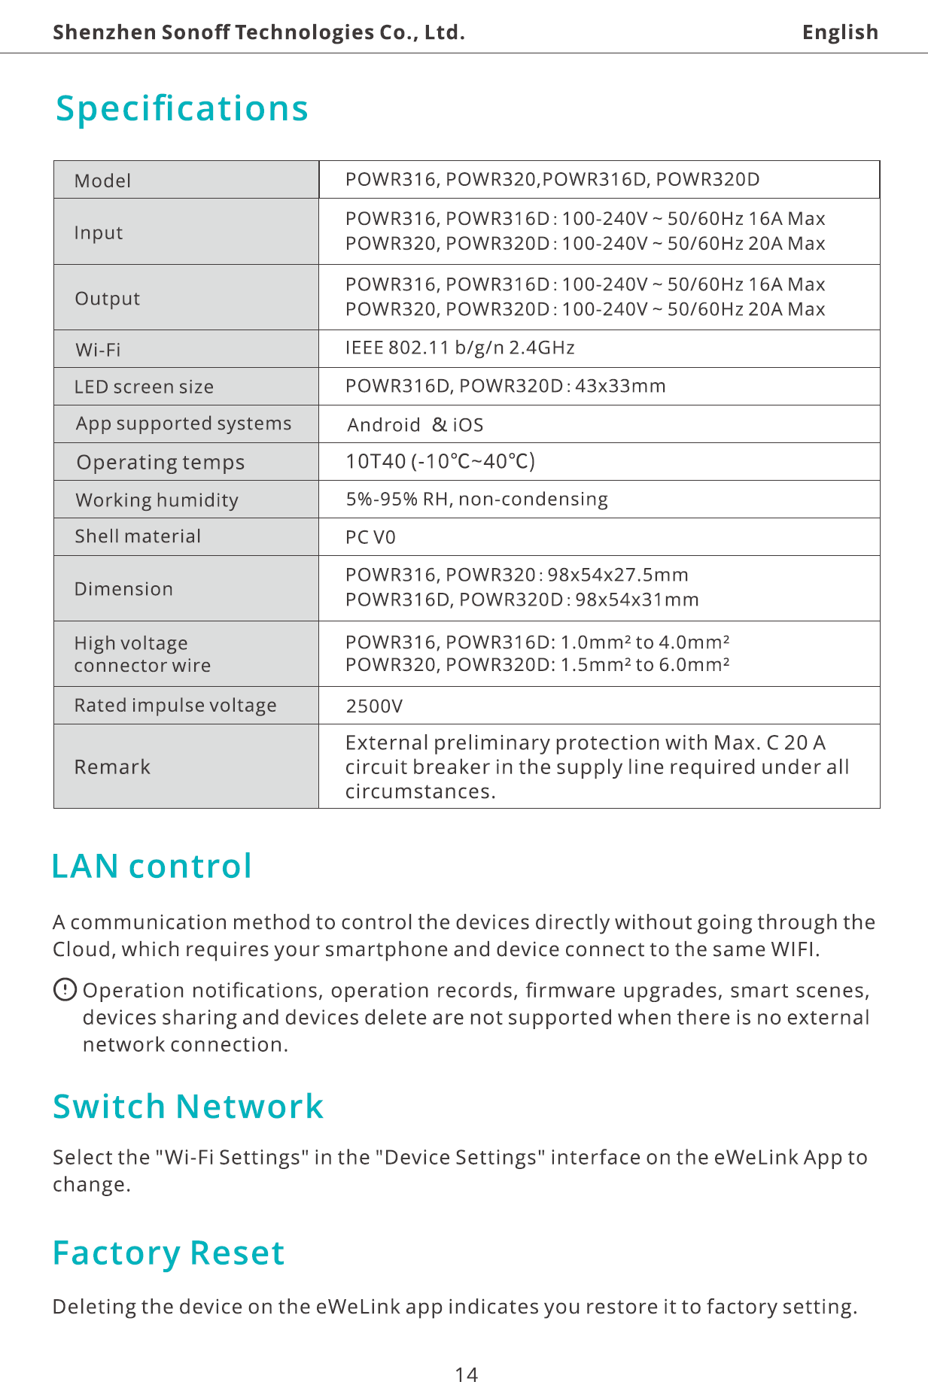
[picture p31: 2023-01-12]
manuals/SONOFF-POW-Elite.png

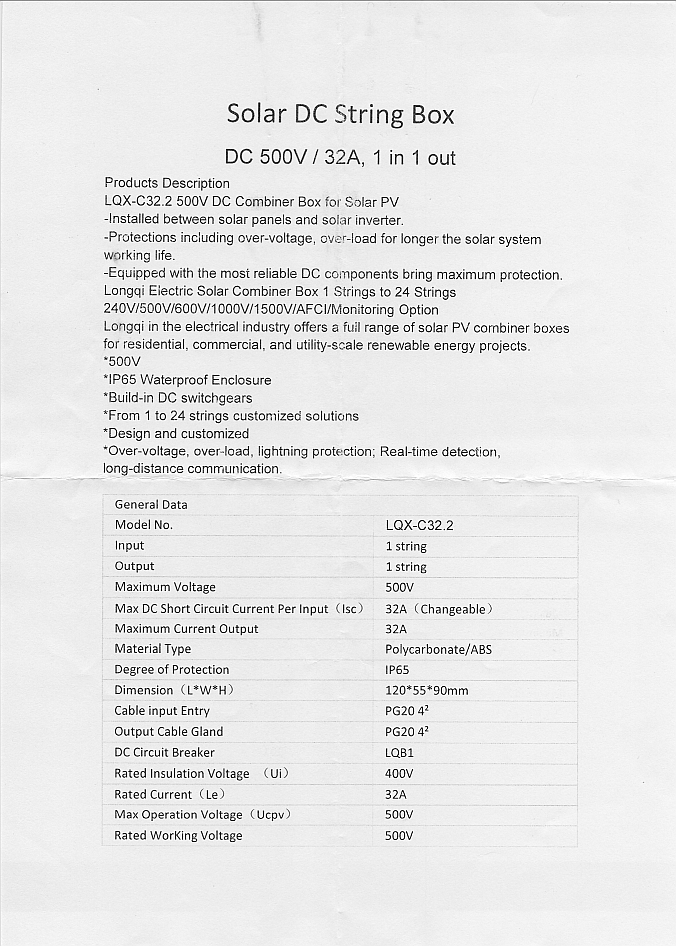
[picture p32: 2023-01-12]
manuals/SolarCircuitBreaker.png

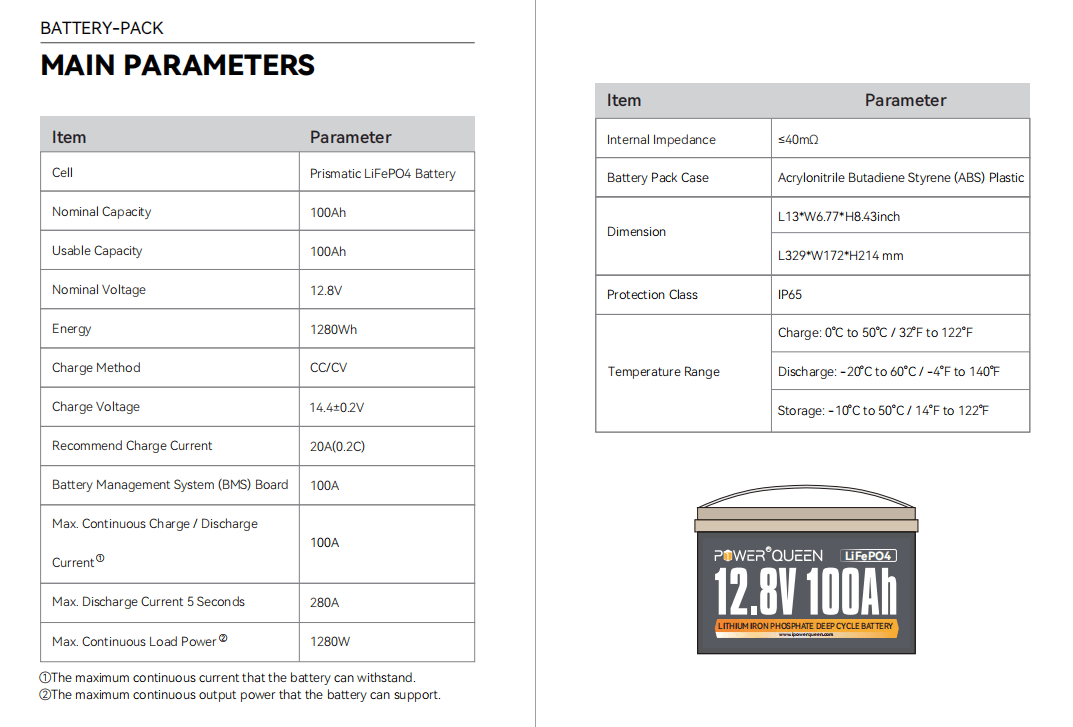
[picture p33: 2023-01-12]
manuals/PowerQueen100Ah.png

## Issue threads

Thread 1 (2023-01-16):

m5paper - solar dashboard

kovi44, 2023-01-16:
Hi,

let me say, that I really like your pv dashboard. I would like to implement your piece of code / software also for my Huawei inverter. I got mqtt reports from inverter. I just checked your code and I understand it correctly then you use some kind of IObroker as mediator between mqtt and m5paper. Did  you consider to connect it directly with mqtt? Is there any limitation? Or whz did you decide to handle it via iobroker?
Thanks
Lukas

Bastelschlumpf, 2023-01-19:
Hello,

If your Huawei inverter has the possibility to connect to a MQTT
server then it should be no problem to display the data later on a M5Paper.
later.

IoBroker is a home control software that runs on a Raspberry for me.
Have a look at https://www.iobroker.net
My inverter is not able to send MQTT so I had to realize the mqqtbridge
with an ESP32.

With my IoBroker there is a MQTT adapter which serves as a server and here you can
activate a history function for the received values, so that you can check the
history data.
Then you have to install a so called 'simple-api' adapter with which you can use a simple
simple http query and get the IoBroker data back as json.

http://server:port/query/mqtt.0.bmv.H17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

In the M5Paper ESP32 I then read the desired MQTT data and display it using canvas.

I hope the information helps.
Greetings Ebby

Closed 2023-01-18.

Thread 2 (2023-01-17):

Arduino IDE - error to compile

kovi44, 2023-01-17:
Hi,

may I kindly ask for help to be able to compile your arduino sketch for m5paper
I always get an error related to RTC or time
Which libraries should I use to be able to compile it? I guess the issue is with RTClib, but not sure

Thanks a lot
Lukas

kovi44, 2023-01-18:
solved, used different version of RTClib

Closed 2023-01-18.

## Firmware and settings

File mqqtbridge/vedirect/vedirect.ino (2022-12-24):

/*
   Copyright (C) 2022 SFini

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
   You should have received a copy of the GNU General Public License
   along with this program.  If not, see <http://www.gnu.org/licenses/>.
*/
/**
  * @file vedirect.ino 
  *
  * ve.direct to MQQT bridge
  */
#include <WiFi.h>
#include <PubSubClient.h>
#include <HardwareSerial.h>
#include "vereader.h"

#include "Config.h"
#define USE_CONFIG_OVERRIDE //!< Switch to use ConfigOverride
#ifdef USE_CONFIG_OVERRIDE
  #include "ConfigOverride.h"
#endif

WiFiClient     wifiClient;
PubSubClient   pubSubClient(wifiClient);

VEDirectReader veDirectReader1(Serial1);
VEDirectReader veDirectReader2(Serial2);

#define SEND_EVEREY_MILLIS  10000
#define SEND_STATUS_MILLIS  60000
#define LED_PIN                 2

int     bmvBlockCompleted  = 0;
int     bmvCheckSumOk      = 0;
int     bmvCheckSumError   = 0;
int     bmvMqqtSend        = 0;
int     mpptBlockCompleted = 0;
int     mpptCheckSumOk     = 0;
int     mpptCheckSumError  = 0;
int     mpptMqqtSend       = 0;

/** Connect to the WiFi network */
void SetupWifi() 
{
   delay(10);
   // We start by connecting to a WiFi network
   Serial.println();
   Serial.print("Connecting to ");
   Serial.println(WIFI_SID);

   WiFi.begin(WIFI_SID, WIFI_PW);

   // Wait max 10 seconds for connection
   for (int i = 0; WiFi.status() != WL_CONNECTED && i < 20; i++) {  
      delay(500);
      Serial.print(".");
   }
   Serial.println("");
   if (WiFi.status() != WL_CONNECTED) {
      Serial.println("WiFi connection failed!!!");
   } else {
      Serial.println("WiFi connected");
      Serial.println("IP address: ");
      Serial.println(WiFi.localIP());
   }
}

/** Set the MQQT server */
void SetupMqqt()
{
   pubSubClient.setServer(MQTT_SERVER, MQTT_PORT);
}

/** Checks the wifi and mqqt connection and connect if needed. */
void Reconnect() 
{
   // Reconnect WiFi if needed
   if (WiFi.status() != WL_CONNECTED) {
      WiFi.reconnect();
   }
   
   // Loop until we're reconnected (5 retries)
   for (int i = 0; !pubSubClient.connected() && i < 5; i++) {  
      Serial.print("Attempting MQTT connection...");
      // Attempt to connect
      // If you do not want to use a username and password, change next line to
      // if (client.connect(MQTT_NAME)) {
      if (pubSubClient.connect(MQTT_NAME, MQTT_USER, MQTT_PASSWORD)) {
         Serial.println("connected");
      } else {
         Serial.print("failed, rc=");
         Serial.print(pubSubClient.state());
         Serial.println(" try again in 5 seconds");
         // Wait 5 seconds before retrying
         delay(5000);
      }
   }
   if (!pubSubClient.connected()) {
      Serial.println("MQTT failed!!!");
   }
}

/** Publish one value to the server. */
void Publish(String prefix, String keyword, String value)
{
   // Ignore empty keywords and ignore hex data ':'
   if (!keyword.isEmpty() && keyword[0] != ':') {
      String topic = prefix + "/" + keyword;

      Serial.println((String) "publish: [" + topic + "]=[" + value + "]");
      pubSubClient.publish(topic.c_str(), value.c_str(), true);
      // We need a small delay here otherwise the values will not arrive correctly.
      delay(10);
      yield();
   }
}

/** Main setup function. */
void setup() 
{
   Serial.begin(19200);
   Serial1.begin(19200, SERIAL_8N1, 27, 26);
   Serial2.begin(19200);
   pinMode(LED_PIN, OUTPUT);
   SetupWifi();
   SetupMqqt();
}

/** Main loop
  * Reconnect to the MQQT server if needed.
  * Read the ve.direct serial lines.
  * If the block ist completed and the checksum is ok, 
  * send the keyword value pairs to the server.
  */
void loop() 
{
   static unsigned long ms1 = 0;
   static unsigned long ms2 = 0;
   static unsigned long ms3 = 0;

   veDirectReader1.readLine();
   veDirectReader2.readLine();
   digitalWrite(LED_PIN, LOW);

   if (veDirectReader1.isBlockCompleted()) {
      bmvBlockCompleted++;
      Serial.println("BMV block completed");
      if (!veDirectReader1.isCheckSumOk()) {
         Serial.println(" -> Checksum Error!");
         bmvCheckSumError++;
      } else {
         bmvCheckSumOk++;
         digitalWrite(LED_PIN, HIGH);
         delay(10);
         // Send only every x seconds
         if (millis() - ms1 > SEND_EVEREY_MILLIS) {
            ms1 = millis();
   
            if (!pubSubClient.connected()) {
               Reconnect();
            }
            if (pubSubClient.connected()) {
               Serial.println("BMV: publish to mqqt server.");
               for (int i = 0; i < veDirectReader1.getValueCount(); i++) {
                  Publish("bmv", veDirectReader1.keywords_[i], veDirectReader1.values_[i]);
               }   
               pubSubClient.loop();
               bmvMqqtSend++;
            }
         }
      }
   }
   
   if (veDirectReader2.isBlockCompleted()) {
      mpptBlockCompleted++;
      Serial.println("MPPT block completed");
      if (!veDirectReader2.isCheckSumOk()) {
         Serial.println(" -> Checksum Error!");
         mpptCheckSumError++;
      } else {
         mpptCheckSumOk++;
         digitalWrite(LED_PIN, HIGH);
         delay(10);
         // Send only every x seconds
         if (millis() - ms2 > SEND_EVEREY_MILLIS) {
            ms2 = millis();
            
            if (!pubSubClient.connected()) {
               Reconnect();
            }
            if (pubSubClient.connected()) {
               Serial.println("MPPT: publish to mqqt server.");
               for (int i = 0; i < veDirectReader2.getValueCount() - 1; i++) {
                  Publish("mppt", veDirectReader2.keywords_[i], veDirectReader2.values_[i]);
               }   
               pubSubClient.loop();
               mpptMqqtSend++;
            }
         }
      }
   }
   
   // Send only every x seconds
   if (millis() - ms3 > SEND_STATUS_MILLIS) {
      ms3 = millis();
      
      if (!pubSubClient.connected()) {
         Reconnect();
      }
      if (pubSubClient.connected()) {
         Serial.println("SOLAR: publish status to mqqt server.");
         Publish("bmv/Statistic",  "BlockCompleted", String(bmvBlockCompleted));
         Publish("bmv/Statistic",  "CheckSumOk",     String(bmvCheckSumOk));
         Publish("bmv/Statistic",  "CheckSumError",  String(bmvCheckSumError));
         Publish("bmv/Statistic",  "MqqtSend",       String(bmvMqqtSend));
         Publish("mppt/Statistic", "BlockCompleted", String(mpptBlockCompleted));
         Publish("mppt/Statistic", "CheckSumOk",     String(mpptCheckSumOk));
         Publish("mppt/Statistic", "CheckSumError",  String(mpptCheckSumError));
         Publish("mppt/Statistic", "MqqtSend",       String(mpptMqqtSend));
         pubSubClient.loop();
      }
   }
   yield();
   delay(10); 
}

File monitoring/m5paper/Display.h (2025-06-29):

/*
   Copyright (C) 2022 SFini

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
   You should have received a copy of the GNU General Public License
   along with this program.  If not, see <http://www.gnu.org/licenses/>.
*/
/**
  * @file Display.h
  * 
  * Main class for drawing the content to the e-paper display.
  */
#pragma once
#include "Data.h"
#include "Icons.h"


M5EPD_Canvas canvas(&M5.EPD); // Main canvas of the e-paper

/* Main class for drawing the content to the e-paper display. */
class SolarDisplay
{
protected:
   MyData &myData; //!< Reference to the global data
   int     maxX;   //!< Max width of the e-paper
   int     maxY;   //!< Max height of the e-paper

protected:
   void   DrawCircle            (int32_t x, int32_t y, int32_t r, uint32_t color, int32_t degFrom = 0, int32_t degTo = 360);
   void   DrawIcon              (int x, int y, const uint16_t *icon, int dx = 64, int dy = 64, bool highContrast = false);
   void   DrawGraph             (int x, int y, int dx, int dy, HistoryData &powerHistory, HistoryData &yieldHistory, HistoryData *chargeHistory = NULL);
   String FormatString          (String format, double data, int fillLen = 8);
   String StateOfOperation      (int value);
   String BmvAlarmReason        (int value);   
   String MpptErrorCode         (int value);

   void   DrawHead              (int x, int y, int dx, int dy);
   void   DrawHeadVersion       (int x, int y);
   void   DrawHeadUpdated       (int x, int y);
   void   DrawHeadRSSI          (int x, int y);
   void   DrawHeadBattery       (int x, int y);
   void   DrawBody              (int x, int y, int dx, int dy);
   void   DrawBatteryInfo       (int x, int y, int dx, int dy);
   void   DrawSolarSymbol       (int x, int y, int dx, int dy);
   void   DrawSolarArrow        (int x, int y, int dx, int dy);
   void   DrawGridInfo          (int x, int y, int dx, int dy);
   void   DrawBatterySymbol     (int x, int y, int dx, int dy);
   void   DrawBatteryArrow      (int x, int y, int dx, int dy);
   void   DrawInverterSymbol    (int x, int y, int dx, int dy);
   void   DrawInverterArrow     (int x, int y, int dx, int dy);
   void   DrawHouseSymbol       (int x, int y, int dx, int dy);
   void   DrawGridArrow         (int x, int y, int dx, int dy);
   void   DrawGridSymbol        (int x, int y, int dx, int dy);
   void   DrawSolarInfo         (int x, int y, int dx, int dy);

public:
   SolarDisplay(MyData &md, int x = 960, int y = 540)
      : myData(md)
      , maxX(x)
      , maxY(y)
   {
   }

   void ClearUpdateInfo();
   void Show();
   void ShowWiFiError(String ssid);
};

/* Draw a circle with optional start and end point */
void SolarDisplay::DrawCircle(int32_t x, int32_t y, int32_t r, uint32_t color, int32_t degFrom /* = 0 */, int32_t degTo /* = 360 */)
{
   for (int i = degFrom; i < degTo; i++) {
      double radians = i * PI / 180;
      double px      = x + r * cos(radians);
      double py      = y + r * sin(radians);
      
      canvas.drawPixel(px, py, color);
   }
} 

/* Draw one icon from the binary data */
void SolarDisplay::DrawIcon(int x, int y, const uint16_t *icon, int dx /*= 64*/, int dy /*= 64*/, bool highContrast /*= false*/)
{
   for (int yi = 0; yi < dy; yi++) {
      for (int xi = 0; xi < dx; xi++) {
         uint16_t pixel = icon[yi * dx + xi];

         if (highContrast) {
            if (15 - (pixel / 4096) > 0) canvas.drawPixel(x + xi, y + yi, M5EPD_Canvas::G15);
         } else {
            canvas.drawPixel(x + xi, y + yi, 15 - (pixel / 4096));
         }
      }
   }
}

/* Draw a graph with x- and y-axis and values */
void SolarDisplay::DrawGraph(int x, int y, int dx, int dy, HistoryData &powerHistory, HistoryData &yieldHistory, HistoryData *chargeHistory /*= NULL*/)
{
   String yMinString  = "0"                              + powerHistory.unitName_;
   String yMaxString1 = String(powerHistory.getMax(), 0) + powerHistory.unitName_;
   String yMaxString2 = String(yieldHistory.getMax(), 0) + yieldHistory.unitName_;
   int    textWidth   = 5 + max(yMaxString1.length() * 8, yMaxString2.length() * 8);
   int    graphX      = x + 5 + textWidth + 5;
   int    graphY      = y + 25;
   int    graphDX     = dx - textWidth - 20;
   int    graphDY     = dy - 25 - 20;

   canvas.setTextSize(2);
   canvas.drawString      (yMaxString2, x + dx - 13, graphY - 15);   
   canvas.drawRightString (yMaxString1, x + 53,      graphY - 15,           1);   
   canvas.drawRightString (yMinString,  x + 53,      graphY + graphDY - 12, 1);   

   canvas.drawLine(x + dx +  8, graphY + 20, x + dx + 18, graphY + 20, M5EPD_Canvas::G15);         
   canvas.drawLine(x + dx +  8, graphY + 20, x + dx +  8, graphY + 30, M5EPD_Canvas::G15);         
   canvas.drawLine(x + dx -  2, graphY + 30, x + dx +  8, graphY + 30, M5EPD_Canvas::G15);         
   canvas.drawLine(x + dx + 18, graphY + 20, x + dx + 18, graphY + 25, M5EPD_Canvas::G15);         
   canvas.drawLine(x + dx + 18, graphY + 25, x + dx + 28, graphY + 25, M5EPD_Canvas::G15);         

   canvas.drawRect(graphX, graphY, graphDX, graphDY, M5EPD_Canvas::G15);   

   if (powerHistory.size_ > 0) {
      String oldDay;
      float  xStep = (float) graphDX / (float) powerHistory.size_;
      
      canvas.setTextSize(1);
      for (int i = 0; i < powerHistory.size_; i++) {
         DateTime date = powerHistory.dates_[i];
         String   day  = String(date.day());
         
         if (oldDay != day && date.hour() >= 12) {
            int xPos = graphX - 3 + i * xStep;
            
            oldDay = day;
            if (xPos > graphX) {
               canvas.drawCentreString(day, xPos, graphY + graphDY + 5, 1);
            }
         }
      }
   }

   if (powerHistory.getMax() > 0) {
      float yStep = (float) graphDY / (float) powerHistory.getMax();
      
      for (int i = 0; i < powerHistory.size_; i++) {
         float yValue   = powerHistory.values_[i];
         float yValueDY = (float) graphDY / (float) powerHistory.getMax();
         float xPos     = (float) graphX + graphDX / (float) powerHistory.size_ * i;
         float yPos     = (float) graphY + graphDY - (float) (yValue) * yValueDY;
   
         if (yPos > graphY + graphDY) yPos = graphY + graphDY;
         if (yPos < graphY)           yPos = graphY;
   
         if (i > 0) {
            canvas.drawLine(xPos, graphY + graphDY, xPos, yPos, M5EPD_Canvas::G15);         
            // Serial.printf("GraphLine: %d %f %d, %d\n", i, yValue, (int) xPos, (int) yPos);
         }
      }
   }
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

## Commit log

2022-12-11 First big version
    [VictronMQQTBridge.fzz]
2022-12-18 - Historical data
    - Error handling
    - Daily yield
    [Display.h]
2023-01-01 Show charge history in the solar part
2023-01-05 WiFi error message in case of WiFi connection problems.
    [Display.h, m5paper.ino]
2023-01-10 The circuit breaker needs a touch-proof cover
    [CircuitBrakeBox.stl]
2023-01-13 Enable wakeup-button
2023-01-21 Added some thermo images with flir camera
2023-01-21 Switch on the front lighting briefly so that you can recognize a start.
2023-01-22 Power usage max 3kWh
2023-02-04 Save battery at night.
2023-02-09 Max power consumption also to 5kWh per day
2023-02-16 Battery fully cycle from 10% to 90%
2024-03-19 Better battery indicator
2025-06-28 More M5Paper board and lib information and remove a crash
2025-06-29 Save more battery with update at day every 1 hour and night every 2 hours

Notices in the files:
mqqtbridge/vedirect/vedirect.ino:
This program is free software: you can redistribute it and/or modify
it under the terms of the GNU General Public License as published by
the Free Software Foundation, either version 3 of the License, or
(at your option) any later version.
